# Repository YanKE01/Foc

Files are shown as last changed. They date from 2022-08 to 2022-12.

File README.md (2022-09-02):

# FOC驱动设计

[![forthebadge]()](https://forthebadge.com)[![forthebadge]()](https://forthebadge.com)

测试平台：

* 硬件：STM32F401CCU6
* 软件：RT thread 4.1.0

目录说明：

* Doc：存放相关数据手册
* HardWare：存放硬件设计
* SoftWare：存放软件设计

# 开源项目支持

simplefoc：https://docs.simplefoc.com/docs_chinese/

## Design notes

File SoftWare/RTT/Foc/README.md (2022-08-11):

# Foc For Rt Thread

测试平台：RT thread 4.1.0

## 硬件资源分配

## 声明

本项目采用外部12MHZ

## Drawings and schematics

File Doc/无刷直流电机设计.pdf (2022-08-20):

## 硬件设计

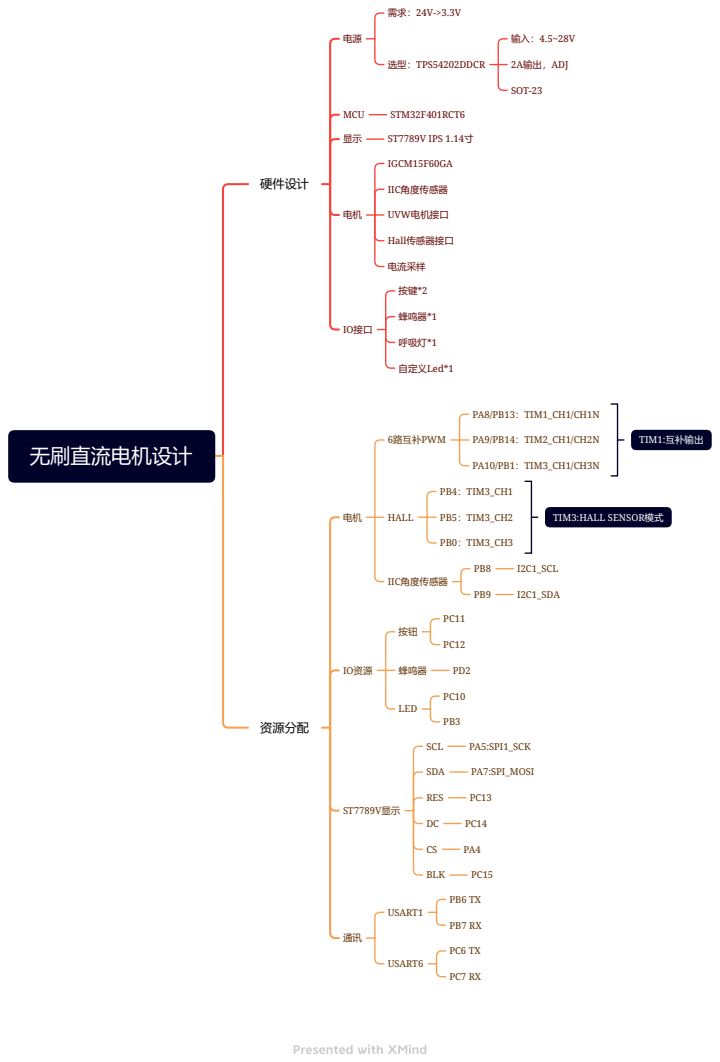
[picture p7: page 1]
无刷直流电机设计; MCU; 选型：TPS54202DDCR; STM32F401RCT6; 2A输出，ADJ; ST7789V IPS 1.14寸; IGCM15F60GA; IO接口; 蜂鸣器*1; SOT-23; 资源分配; 6路互补PWM; PA8/PB13：TIM1_CH1/CH1N; PA9/PB14：TIM2_CH1/CH2N; PA10/PB1：TIM3_CH1/CH3N; HALL; PB4：TIM3_CH1; PB5：TIM3_CH2; PB0：TIM3_CH3; IO资源; 呼吸灯*1; 自定义Led*1; IIC角度传感器; UVW电机接口; Hall传感器接口; ST7789V显示; SCL; SDA; RES; BLK; PA5:SPI1_SCK; PA7:SPI_MOSI; 蜂鸣器; LED; TIM3:HALL SENSOR模式; TIM1:互补输出; 电流采样; I2C1_SCL; I2C1_SDA; USART1; USART6

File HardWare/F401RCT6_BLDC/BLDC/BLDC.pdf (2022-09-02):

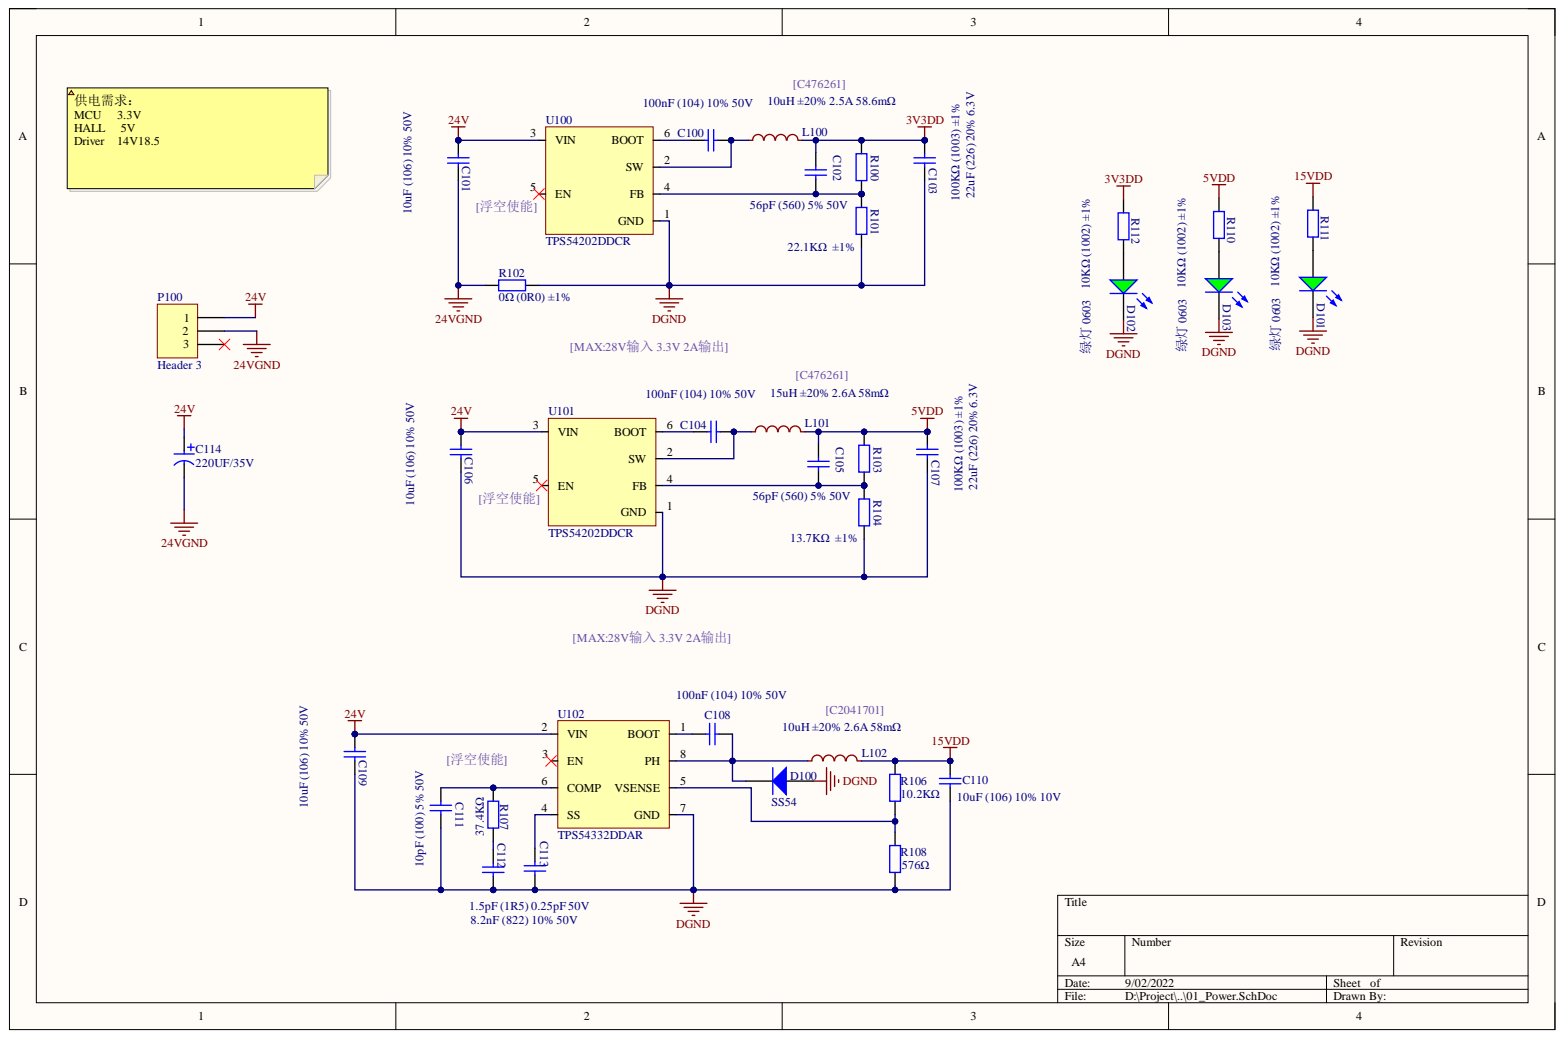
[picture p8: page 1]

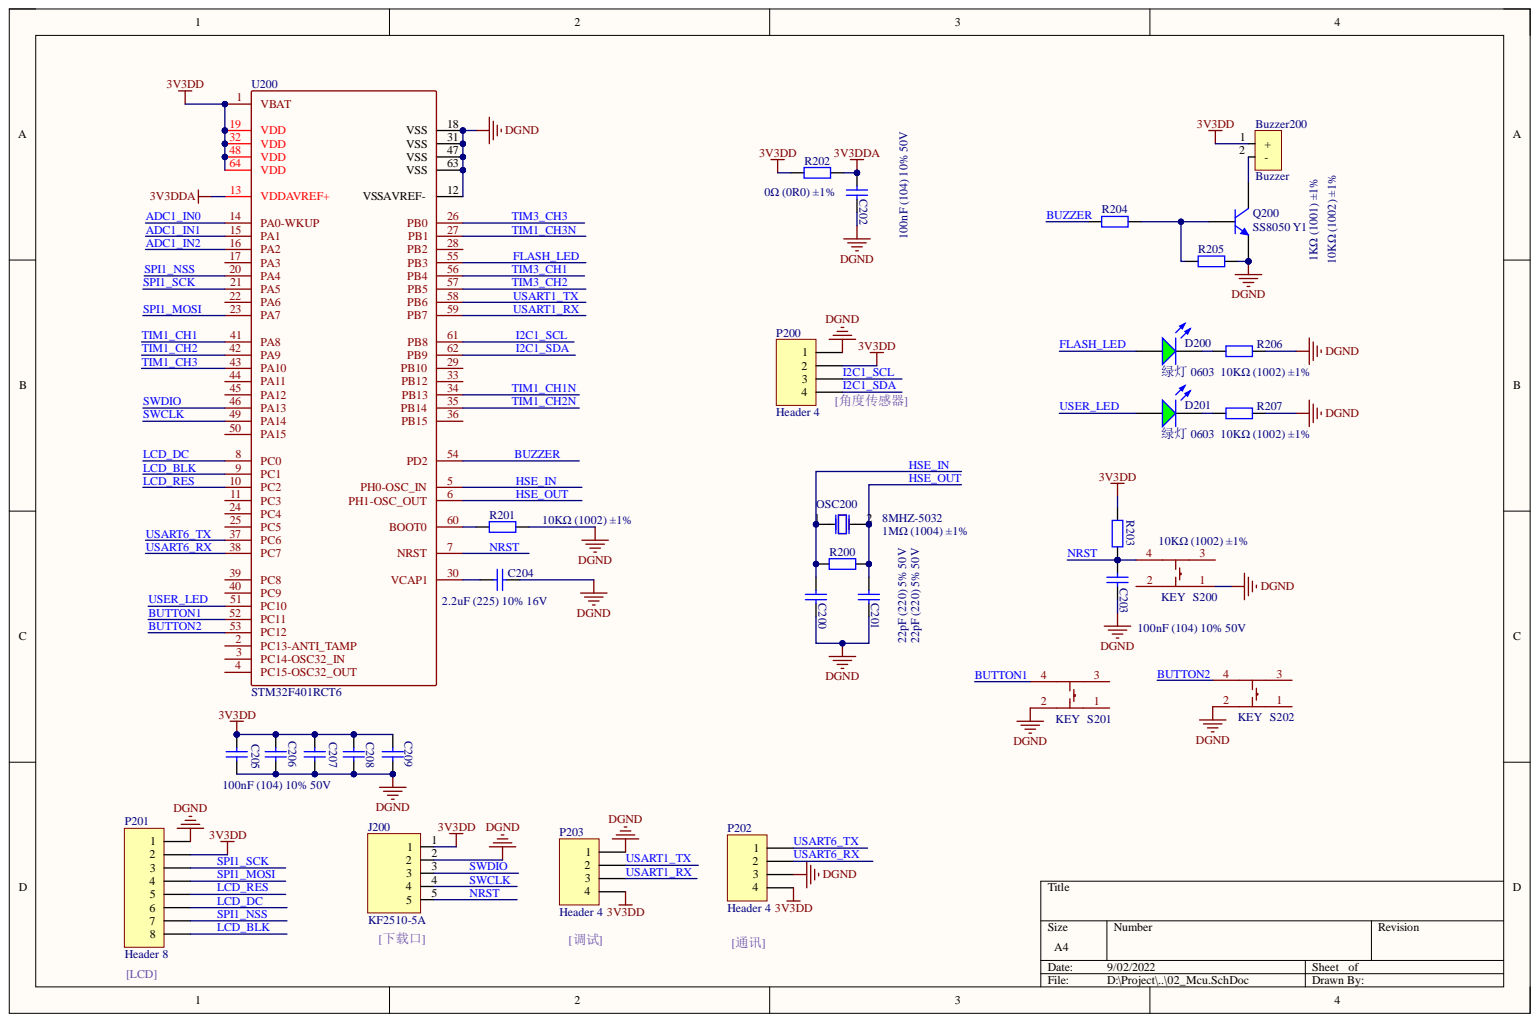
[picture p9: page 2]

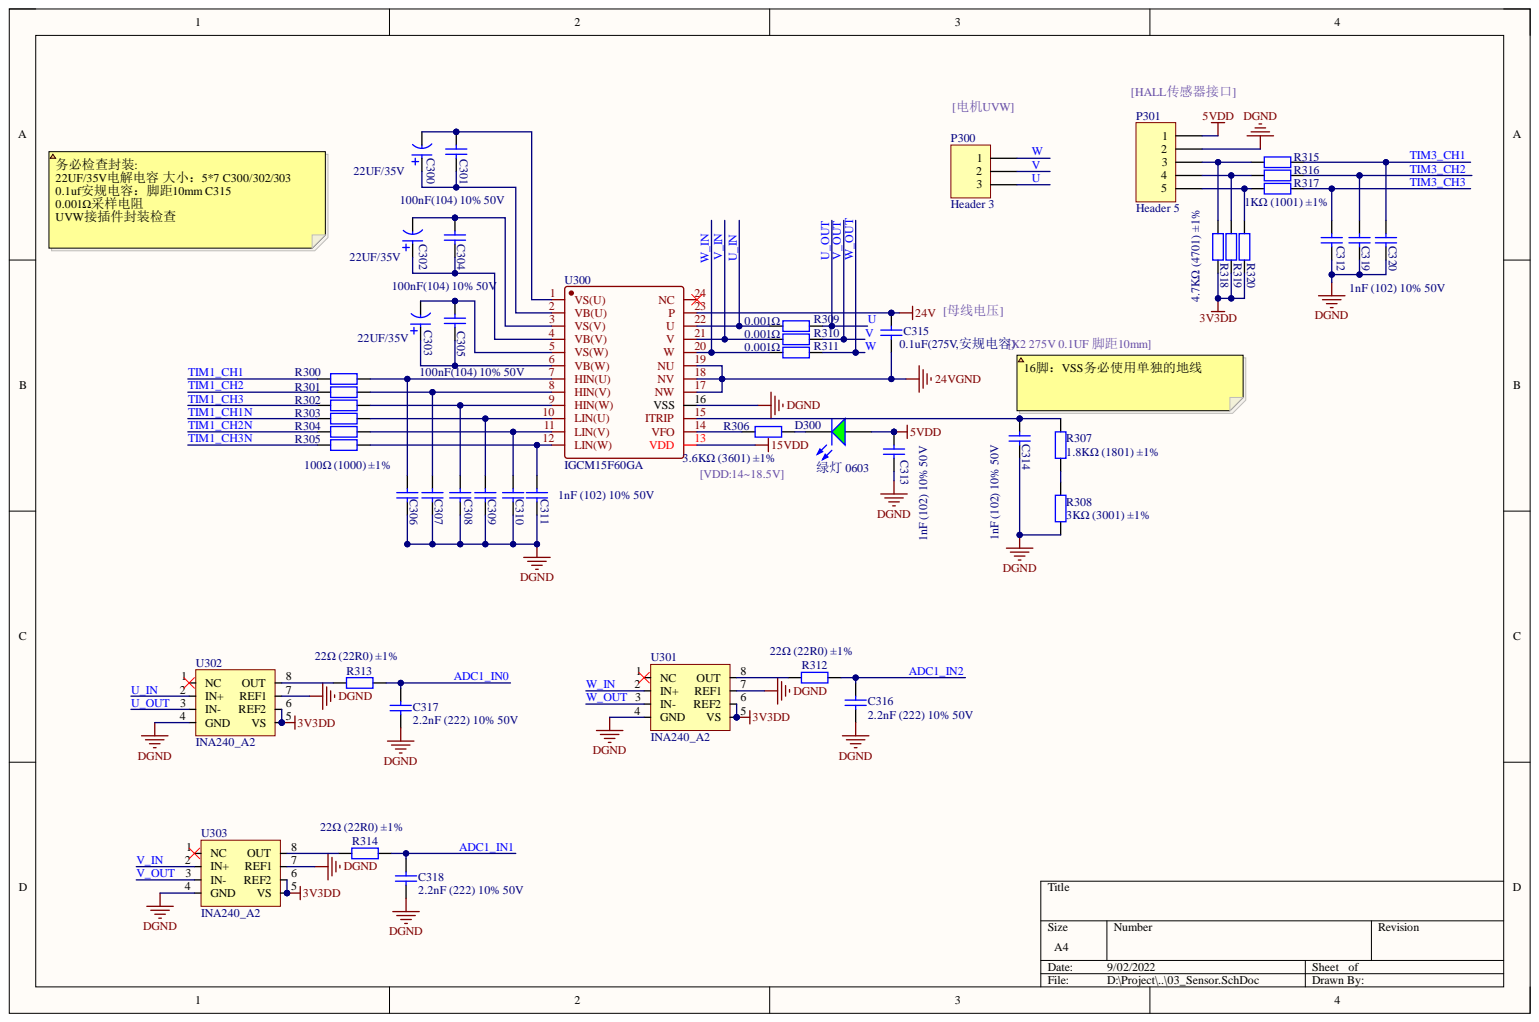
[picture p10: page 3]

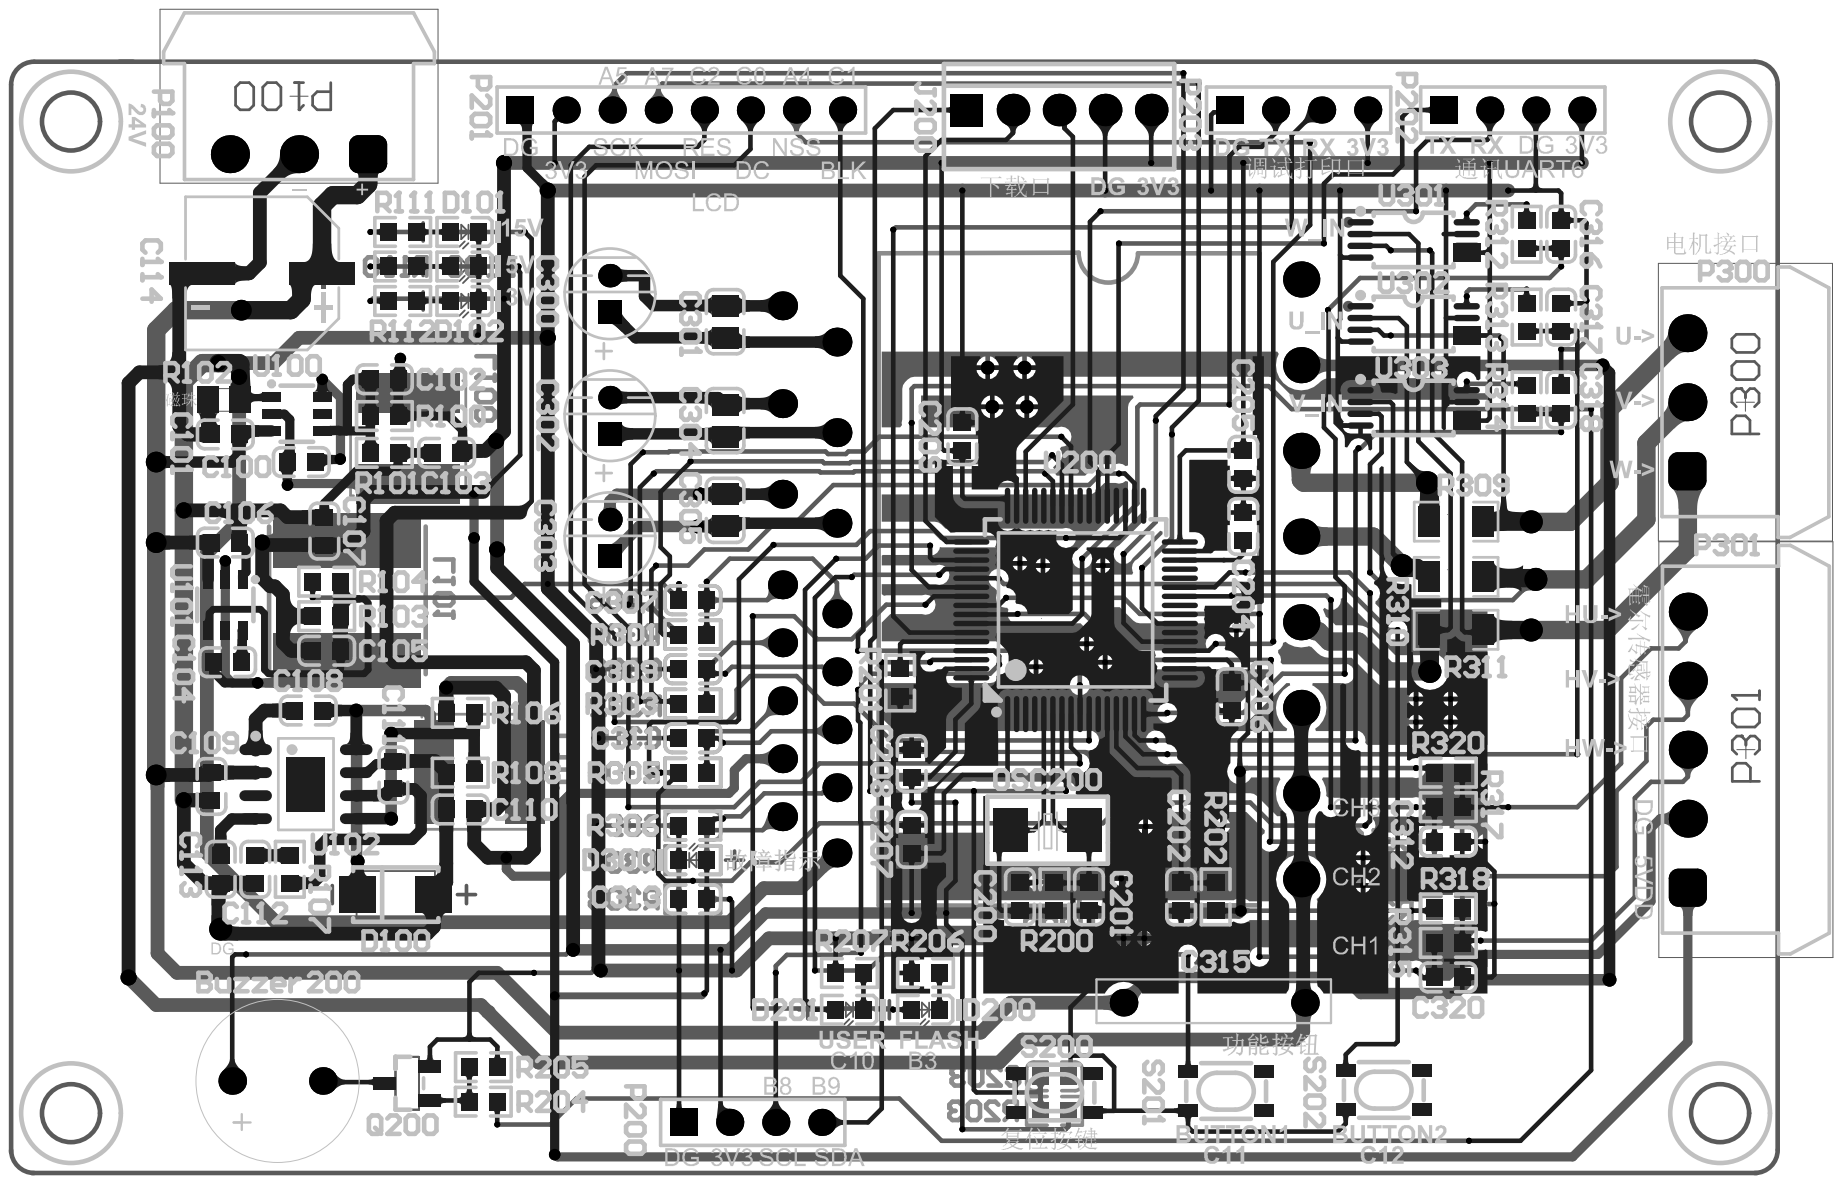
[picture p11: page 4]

Comment | Description | Designator | Footprint | LibRef | Quantity
Buzzer | | Buzzer200 | buzzer-0905 | Buzzer | 1
100nF (104) 10% 50V | 贴片电容 | C100, C104, C108, C202, C203 | 0603_C | 0603 100nF (104) 10% 50V | 5
10uF (106) 10% 50V | 贴片电容 | C101, C106, C109 | 0603_C | 0603 10uF (106) 10% 10V | 3
56pF (560) 5% 50V | 贴片电容 | C102, C105 | 0603_C | 0603 56pF (560) 5% 50V | 2
22uF (226) 20% 6.3V | 贴片电容 | C103, C107 | 0603_C | 0603 22uF (226) 20% 6.3V | 2
10uF (106) 10% 10V | 贴片电容 | C110 | 0603_C | 0603 10uF (106) 10% 10V | 1
10pF (100) 5% 50V | 贴片电容 | C111 | 0603_C | 0603 10pF (100) 5% 50V | 1
1.5pF (1R5) 0.25pF 50V | 贴片电容 | C112 | 0603_C | 0603 1.5pF (1R5) 0.25pF 50V | 1
8.2nF (822) 10% 50V | 贴片电容 | C113 | 0603_C | 0603 8.2nF (822) 10% 50V | 1
220UF/35V | 电解电容 | C114 | CAP_L8.3_W8.3 | CAP2 | 1
22pF (220) 5% 50V | 贴片电容 | C200, C201 | 0603_C | 0603 22pF (220) 5% 50V | 2
2.2uF (225) 10% 16V | 贴片电容 | C204 | 0603_C | 0603 2.2uF (225) 10% 16V | 1
100nF (104) 10% 50V | 贴片电容 | C205, C206, C207, C208, C209 | LC-0603_C | 0603 100nF (104) 10% 50V | 5
22UF/35V | 电解电容 | C300, C302, C303 | 电解电容5*7 | CAP2 | 3
100nF(104) 10% 50V | 贴片电容 | C301, C304, C305 | 0805_C | 0805 100nF(104) 10% 50V | 3
1nF (102) 10% 50V | 贴片电容 | C306, C307, C308, C309, C310, C311, C312, C313, C314, C319, C320 | 0603_C | 0603 1nF (102) 10% 50V | 11
0.1uF(275V,安规电 容) | 贴片电容 | C315 | X2_安规电容_10MM | 0603 100nF (104) 10% 50V | 1
2.2nF (222) 10% 50V | 贴片电容 | C316, C317, C318 | 0603_C | 0603 2.2nF (222) 10% 50V | 3
SS54 | 二极管 | D100 | SMA(DO-214AC)_S1 | SMA(DO-214AC) SS54 | 1
绿灯 0603 | 发光二极管 | D101, D102, D103, D200, D201, D300 | 0603_LED_S1 | 0603 绿灯 | 6
KF2510-5A | | J200 | KF2510-5A | KF2510-5A | 1
10uH ±20% 2.5A 58.6mΩ | | L100 | L_SMD_L6_W6 | L | 1
15uH ±20% 2.6A 58mΩ | | L101 | L_SMD_L8_W8 | L | 1
10uH ±20% 2.6A 58mΩ | | L102 | L_SMD_L6_W6 | L | 1
8MHZ-5032 | | OSC200 | 8MHZ-5032 | 8MHZ-5032 | 1
Header 3 | Header, 3-Pin | P100, P300 | KF2EDGK-3.81-WI-3P | Header 3 | 2
Header 4 | Header, 4-Pin | P200, P202, P203 | HDR1X4 | Header 4 | 3
Header 8 | Header, 8-Pin | P201 | HDR1X8 | Header 8 | 1
Header 5 | Header, 5-Pin | P301 | KF2EDGK-3.81-WI-5P | Header 5 | 1
SS8050 Y1 | 三极管 | Q200 | SOT-23(SOT-23-3) | SOT-23 SS8050 Y1 | 1
100KΩ (1003) ±1% | 贴片电阻 | R100, R103 | 0603_R | 0603 100KΩ (1003) 1% | 2
22.1KΩ ±1% | 贴片电阻 | R101 | 0603_R | 0603 100KΩ (1003) 1% | 1
0Ω (0R0) ±1% | 贴片电阻 | R102 | LC-0805 | 0603 0Ω (0R0) 1% | 1
13.7KΩ ±1% | 贴片电阻 | R104 | 0603_R | 0603 100KΩ (1003) 1% | 1
10.2KΩ | 贴片电阻 | R106 | 0603_R | 0603 10KΩ (1002) 1% | 1
37.4KΩ | 贴片电阻 | R107 | 0603_R | 0603 10KΩ (1002) 1% | 1
576Ω | 贴片电阻 | R108 | 0603_R | 0603 10KΩ (1002) 1% | 1
10KΩ (1002) ±1% | 贴片电阻 | R110, R111, R112, R201, R203, R205, R206, R207 | 0603_R | 0603 10KΩ (1002) 1% | 8
1MΩ (1004) ±1% | 贴片电阻 | R200 | 0603_R | 0603 1MΩ (1004) 1% | 1
0Ω (0R0) ±1% | 贴片电阻 | R202 | 0603_R | 0603 0Ω (0R0) 1% | 1
1KΩ (1001) ±1% | 贴片电阻 | R204, R315, R316, R317 | 0603_R | 0603 1KΩ (1001) 1% | 4
100Ω (1000) ±1% | 贴片电阻 | R300, R301, R302, R303, R304, R305 | 0603_R | 0603 100Ω (1000) 1% | 6
3.6KΩ (3601) ±1% | 贴片电阻 | R306 | 0603_R | 0603 3.6KΩ (3601) 1% | 1
1.8KΩ (1801) ±1% | 贴片电阻 | R307 | 0603_R | 0603 1.8KΩ (1801) 1% | 1
3KΩ (3001) ±1% | 贴片电阻 | R308 | 0603_R | 0603 3KΩ (3001) 1% | 1
0.001Ω | 贴片电阻 | R309, R310, R311 | R1206 | 0805 10KΩ (1002) 1% | 3
22Ω (22R0) ±1% | 贴片电阻 | R312, R313, R314 | 0603_R | 0603 22Ω (22R0) 1% | 3
4.7KΩ (4701) ±1% | 贴片电阻 | R318, R319, R320 | 0603_R | 0603 4.7KΩ (4701) 1% | 3
KEY | 白色方块 | S200, S201, S202 | KEY_WHITE | KEY | 3
TPS54202DDCR | | U100, U101 | TPS54202DDCR | TPS54202DDCR | 2
TPS54332DDAR | | U102 | TPS54332DDAR | TPS54332DDAR | 1
STM32F401RCT6 | | U200 | STM32F401RCT6 | STM32F401RCT6 | 1
IGCM15F60GA | | U300 | IGCM15F60GA | IGCM15F60GA | 1
INA240_A2 | | U301, U302, U303 | INA240A2PWR | INA240_A2 | 3

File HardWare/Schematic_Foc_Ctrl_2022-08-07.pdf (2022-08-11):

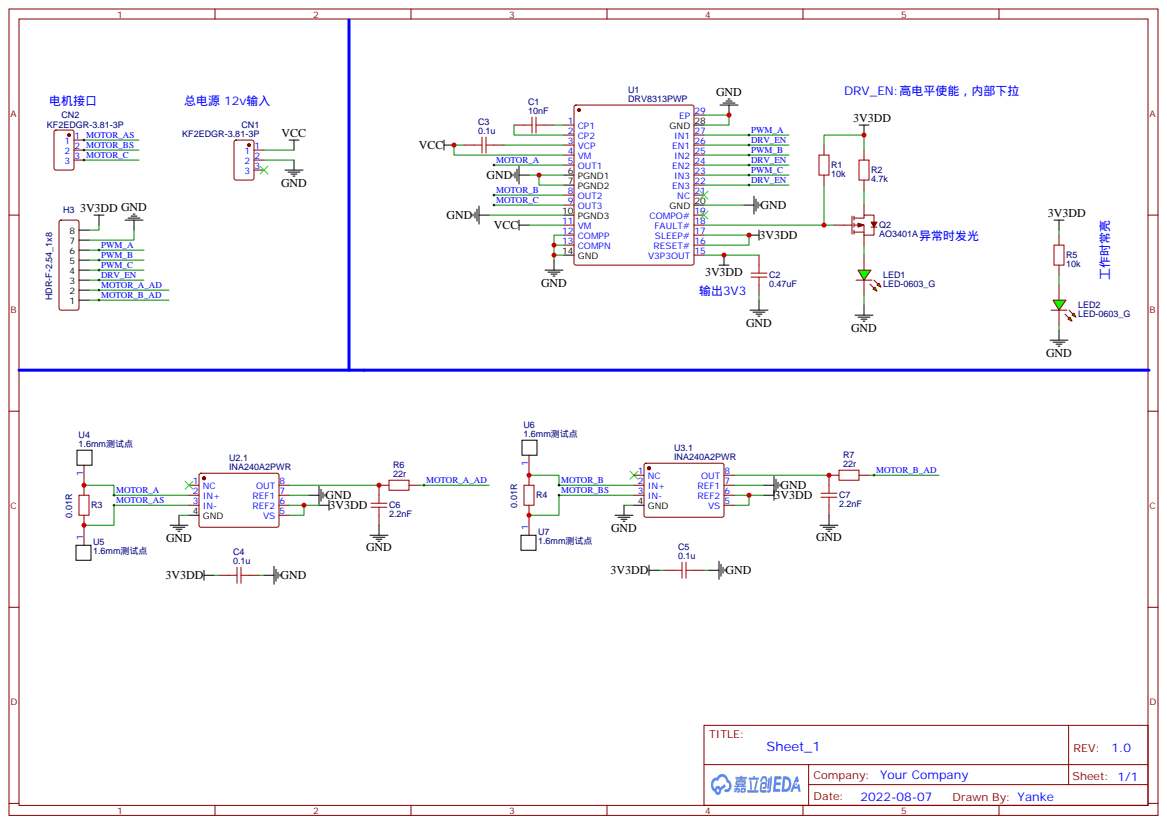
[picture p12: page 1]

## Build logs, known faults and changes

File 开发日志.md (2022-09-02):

# FOC驱动开发日志

## Hall传感器

Hall传感器120°布置下的真值表

image-20220823111513646 width="100px" height="100px"



**极对数：**

电机每次转过一个磁极的时候，就会输出6中状态。

正点的电机极对数为2，就是一圈会有12个状态

电角度等于机械角度乘以极对数，

## 硬件缺陷记录

### 2022年9月2日：

* IPS屏幕距离下载口位置过近，需要调整位置
* HALL 传感器对应的IO丝印未标注
* 英飞凌的驱动故障指示灯需要修改

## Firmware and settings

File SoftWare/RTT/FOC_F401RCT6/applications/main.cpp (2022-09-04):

/*
 * Copyright (c) 2006-2022, RT-Thread Development Team
 *
 * SPDX-License-Identifier: Apache-2.0
 * 命名规范：https://zh-google-styleguide.readthedocs.io/en/latest/google-cpp-styleguide/naming/
 * Change Logs:
 * Date           Author       Notes
 * 2022-09-02     RT-Thread    first version
 */

#include <rtthread.h>
#include <board.h>
#include <rtdevice.h>
#include "include/task.h"
#include "tim.h"
int main(void)
{
    MX_TIM1_Init();
    TaskStartUp();
    return RT_EOK;
}

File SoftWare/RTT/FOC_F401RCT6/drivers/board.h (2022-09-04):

/*
 * Copyright (c) 2006-2022, RT-Thread Development Team
 *
 * SPDX-License-Identifier: Apache-2.0
 *
 * Change Logs:
 * Date           Author       Notes
 * 2022-09-02     RealThread   first version
 */

#ifndef __BOARD_H__
#define __BOARD_H__

#include <stm32f4xx.h>
#include <drv_common.h>


#ifdef __cplusplus
extern "C"
{
#endif

/*-------------------------- CHIP CONFIG BEGIN --------------------------*/

#define CHIP_FAMILY_STM32
#define CHIP_SERIES_STM32F4
#define CHIP_NAME_STM32F401RC

/*-------------------------- CHIP CONFIG END --------------------------*/

/*-------------------------- ROM/RAM CONFIG BEGIN --------------------------*/

#define ROM_START              ((uint32_t)0x08000000)
#define ROM_SIZE               (256 * 1024)
#define ROM_END                ((uint32_t)(ROM_START + ROM_SIZE))

#define RAM_START              (0x20000000)
#define RAM_SIZE               (64 * 1024)
#define RAM_END                (RAM_START + RAM_SIZE)

/*-------------------------- ROM/RAM CONFIG END --------------------------*/

/*-------------------------- CLOCK CONFIG BEGIN --------------------------*/

#define BSP_CLOCK_SOURCE                  ("HSI")
#define BSP_CLOCK_SOURCE_FREQ_MHZ         ((int32_t)0)
#define BSP_CLOCK_SYSTEM_FREQ_MHZ         ((int32_t)84)

/*-------------------------- CLOCK CONFIG END --------------------------*/

/*-------------------------- UART CONFIG BEGIN --------------------------*/

/** After configuring corresponding UART or UART DMA, you can use it.
 *
 * STEP 1, define macro define related to the serial port opening based on the serial port number
 *                 such as     #define BSP_USING_UART1
 *
 * STEP 2, according to the corresponding pin of serial port, define the related serial port information macro
 *                 such as     #define BSP_UART1_TX_PIN       "PA9"
 *                             #define BSP_UART1_RX_PIN       "PA10"
 *
 * STEP 3, if you want using SERIAL DMA, you must open it in the RT-Thread Settings.
 *                 RT-Thread Setting -> Components -> Device Drivers -> Serial Device Drivers -> Enable Serial DMA Mode
 *
 * STEP 4, according to serial port number to define serial port tx/rx DMA function in the board.h file
 *                 such as     #define BSP_UART1_RX_USING_DMA
 *
 */

#define BSP_USING_UART1
#define BSP_UART1_TX_PIN       "PB6"
#define BSP_UART1_RX_PIN       "PB7"

/*-------------------------- UART CONFIG END --------------------------*/

/*-------------------------- I2C CONFIG BEGIN --------------------------*/

/** if you want to use i2c bus(soft simulate) you can use the following instructions.
 *
 * STEP 1, open i2c driver framework(soft simulate) support in the RT-Thread Settings file
 *
 * STEP 2, define macro related to the i2c bus
 *                 such as     #define BSP_USING_I2C1
 *
 * STEP 3, according to the corresponding pin of i2c port, modify the related i2c port and pin information
 *                 such as     #define BSP_I2C1_SCL_PIN    GET_PIN(port, pin)   ->   GET_PIN(C, 11)
 *                             #define BSP_I2C1_SDA_PIN    GET_PIN(port, pin)   ->   GET_PIN(C, 12)
 */

/*#define BSP_USING_I2C1*/
#ifdef BSP_USING_I2C1
#define BSP_I2C1_SCL_PIN    GET_PIN(port, pin)
#define BSP_I2C1_SDA_PIN    GET_PIN(port, pin)
#endif

/*#define BSP_USING_I2C2*/
#ifdef BSP_USING_I2C2
#define BSP_I2C2_SCL_PIN    GET_PIN(port, pin)
#define BSP_I2C2_SDA_PIN    GET_PIN(port, pin)
#endif

/*-------------------------- I2C CONFIG END --------------------------*/

/*-------------------------- SPI CONFIG BEGIN --------------------------*/

/** if you want to use spi bus you can use the following instructions.
 *
 * STEP 1, open spi driver framework support in the RT-Thread Settings file
 *
 * STEP 2, define macro related to the spi bus
 *                 such as     #define BSP_USING_SPI1
 *
 * STEP 3, copy your spi init function from stm32xxxx_hal_msp.c generated by stm32cubemx to the end of board.c file
 *                 such as     void HAL_SPI_MspInit(SPI_HandleTypeDef* hspi)
 *
 * STEP 4, modify your stm32xxxx_hal_config.h file to support spi peripherals. define macro related to the peripherals
 *                 such as     #define HAL_SPI_MODULE_ENABLED
 */

#define BSP_USING_SPI1
/*#define BSP_USING_SPI2*/
/*#define BSP_USING_SPI3*/

/*-------------------------- SPI CONFIG END --------------------------*/

/*-------------------------- QSPI CONFIG BEGIN --------------------------*/
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

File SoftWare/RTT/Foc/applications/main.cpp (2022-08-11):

/*
 * Copyright (c) 2006-2022, RT-Thread Development Team
 *
 * SPDX-License-Identifier: Apache-2.0
 *
 * Change Logs:
 * Date           Author       Notes
 * 2022-08-11     RT-Thread    first version
 */

#include <rtthread.h>
#include "hal.h"
#include "task.h"
#include "encoder.h"
int main(void)
{
    HalInit();
    TaskInit();

    return RT_EOK;
}

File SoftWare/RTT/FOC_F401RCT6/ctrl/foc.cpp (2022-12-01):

/*
 * Copyright (c) 2006-2021, RT-Thread Development Team
 *
 * SPDX-License-Identifier: Apache-2.0
 *
 * Change Logs:
 * Date           Author       Notes
 * 2022-09-03     SkyLin       the first version
 */
#include "foc.h"
#include "tim.h"
#include <math.h>
#include "arm_math.h"

/**
 * @brief Construct a new Foc:: Foc object
 *
 * @param voltagePowerSupply 母线电压
 */
Foc::Foc(float voltagePowerSupply)
{
    this->voltagePowerSupply = voltagePowerSupply;
}

/**
 * @brief 归一化角度
 *
 * @param angle
 * @return float
 */
float Foc::NormalizeAngle(float angle)
{
    float a = fmod(angle, _2PI);
    return a >= 0 ? a : (a + _2PI);
}

void Foc::ParkAntiOperate(float ud, float uq, float theta)
{
    ualpha = ud * arm_cos_f32(theta) - uq * arm_sin_f32(theta);
    ubeta = ud * arm_sin_f32(theta) + uq * arm_cos_f32(theta);
}


/**
 * @brief SVPWM计算
 * 
 * @param uq 
 * @param ud 
 * @param angleEl 
 */
void Foc::Svpwm(float uq, float ud, float angleEl)
{
    if (uq < 0)
    {
        angleEl = NormalizeAngle(angleEl - _PI_2); //顺时针
    }
    else
    {
        angleEl = NormalizeAngle(angleEl + _PI_2); //逆时针
    }

    // 1-反park变换
    ParkAntiOperate(ud, uq, angleEl);

    // 2-计算参考电压矢量，限制其在0~1,并且为保证最大不失真 需要限制参考矢量在内切圆中 (根号3)/3
    uref = sqrt(ualpha * ualpha + ubeta * ubeta) / voltagePowerSupply;
    if (uref > 0.577f)
    {
        uref = 0.577f;
    }


    // 3-计算所在扇区
    sector = (angleEl / _PI_3) + 1;

    // 4-计算相邻矢量的作用时间
    t1 = _SQRT3 * arm_sin_f32(sector * _PI_3 - angleEl) * uref;
    t2 = _SQRT3 * arm_sin_f32(angleEl - (sector - 1.0) * _PI_3) * uref;
    t0 = 1 - t1 - t2;

    // 5-根据7段PWM计算每一项的作用时间
    switch (sector)
    {
    case 1:
        ta = t1 + t2 + t0 / 2;
        tb = t2 + t0 / 2;
        tc = t0 / 2;
        break;
    case 2:
        ta = t1 + t0 / 2;
        tb = t1 + t2 + t0 / 2;
        tc = t0 / 2;
        break;
    case 3:
        ta = t0 / 2;
        tb = t1 + t2 + t0 / 2;
        tc = t2 + t0 / 2;
        break;
    case 4:
        ta = t0 / 2;
        tb = t1 + t0 / 2;
        tc = t1 + t2 + t0 / 2;
        break;
    case 5:
        ta = t2 + t0 / 2;
        tb = t0 / 2;
        tc = t1 + t2 + t0 / 2;
        break;
    case 6:
        ta = t1 + t2 + t0 / 2;
        tb = t0 / 2;
        tc = t1 + t0 / 2;
        break;
    default:
        ta = 0;
        tb = 0;
        tc = 0;
        break;
    }

    ccr1 = 100 * ta; // 100是arr的值
    ccr2 = 100 * tb; // 100是arr的值
    ccr3 = 100 * tc; // 100是arr的值

    TIM1->CCR1 = ccr1;
    TIM1->CCR2 = ccr2;
    TIM1->CCR3 = ccr3;
}

Foc::~Foc()
{
}

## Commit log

2022-08-11 first update
    [kconfig-language.txt, kconfig.txt]
2022-08-20 first update pcb
    [01_Power.SchDoc, 02_Mcu.SchDoc, 03_Sensor.SchDoc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]
2022-08-21 update pcb
    [01_Power.SchDoc, 02_Mcu.SchDoc, 03_Sensor.SchDoc]
2022-08-21 fix pcb bug
    [01_Power.SchDoc, 02_Mcu.SchDoc, 03_Sensor.SchDoc]
2022-09-02 update stm32f401rct6
    [01_Power.SchDoc, 02_Mcu.SchDoc, 03_Sensor.SchDoc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]
2022-09-02 add rtt for stm32f401rct6
    [kconfig-language.txt, kconfig.txt]
2022-09-04 update stm32f401rct6 angle operation
2022-11-28 update foc code
    [BLDC.PrjPcb]
2022-12-01 fix pcb
    [01_Power.SchDoc, 03_Sensor.SchDoc]
2022-12-01 foc learn
    [01_Power.SchDoc, 03_Sensor.SchDoc]
